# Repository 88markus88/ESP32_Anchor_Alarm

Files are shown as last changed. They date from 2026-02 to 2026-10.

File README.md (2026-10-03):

# Battery operated ESP32 Anchor Alarm with ePaper Display 
Anchor Alarm with LolinLite ESP32, GPS Module, ePaper Display and setting via rotary encoder

At anchor we like to use an anchor alarm app on the mobile phone. Unfortunately that one has a few disadvantages: it uses up the battery quickly, and sometimes Android likes to stop the app for mysterious reasons, particularly if it is not in the front and the screen on. We could also use nachor alarms embedded in other onboard electronics (e.g. AIS), but I find that to inflexible and using too much energy from our precious house batteries.

Thatˋs why I have come up with an alternative, an GPS based anchor alarm with LiPo battery and an ePaper display. It is run by power saving variant of the ESP32 SOC, the Lolin Lite.

| Overview | Routine Screen | Size Comparison
| :--- | :--- | :-- |
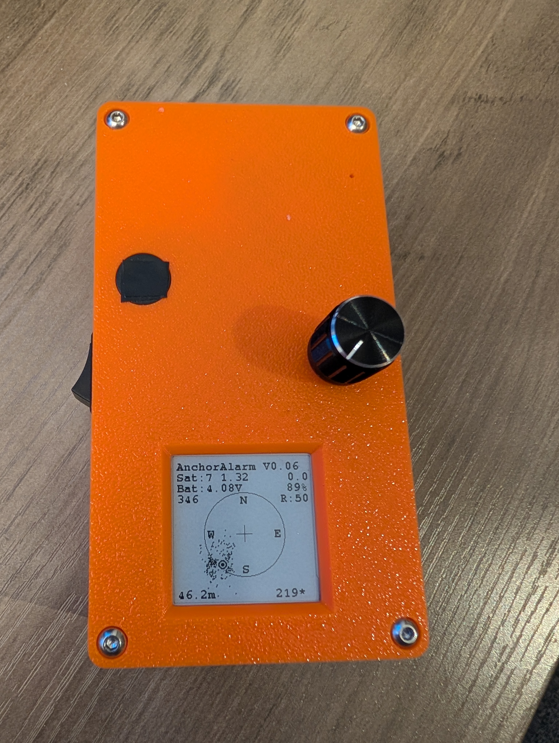
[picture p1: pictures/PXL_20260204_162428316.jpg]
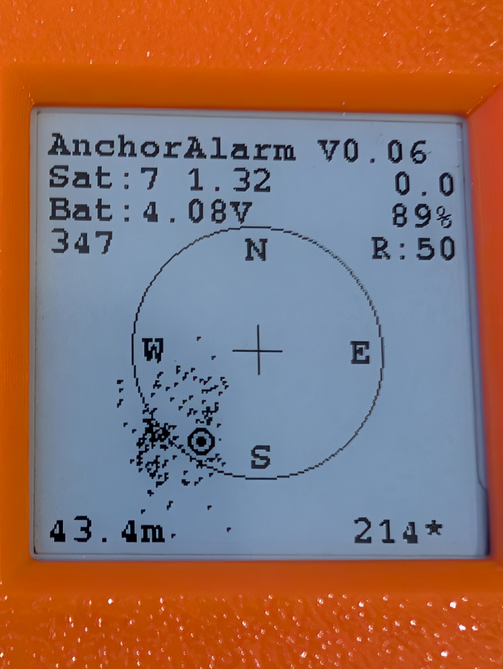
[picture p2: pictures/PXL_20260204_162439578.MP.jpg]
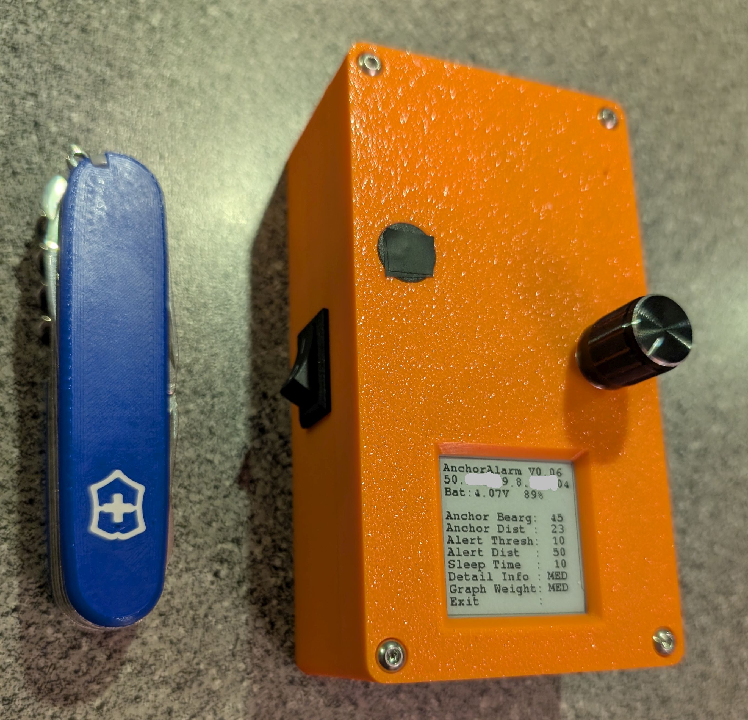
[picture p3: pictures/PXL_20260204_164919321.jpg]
||||

Main components:
- Lolin Lite ESP32: optimized for battery operation while still being inexpensive. It is optimized for battery operation, the module has a very low consumption in deep sleep.
- ePaper Display 1.54" with 200x200 resolution. Sufficiently large for the use case, very low power consumption and pretty good readabilty
- 1800 mAh LiPo battery 52x34x10 mm: sufficient for 30 hours of operation (measured power consumption is 60 mA on avarage)
- GPS module (Ublox NEO-6M, NEO-M8N or alternatively ATGM336H)
- Optional: active GPS antenna
- Rotary Encoder with button for settings
- PCB board: I have recycled a board for the ePaper barograph that I built earlier. I had a few ones left over, all the required pins are exposed (some not properly labeled...)
- 3D printed housing

## Using the Anchor Alarm
Switch on with the toggle switch on the side.
The device will go through a few selftests (including some beeps) 
Then the main menu is shown. Rotate the knob to move through the menu or change values, press it to select.

1: Program name and version<br>
2: Present GPS position in decimal notation<br>
3: Battery voltage and percentage<br>
5: Anchor Bearing - True compass bearing from boat to anchor<br>
6: Anchor Distance - Distance from boat to anchor om meters<br>
7: Alert Threshold - Numeric value that determines how often and how far the boat must be out of the safe circle before an alert is triggered. 10% out of the circle adds 1, 30% out of the circle adds 3 and so on. If the sum of these values is bigger than the Alert Threshold, the alert is triggered<br>
8: Alert Distance - Radius of the safe circle around the anchor in meters <br>
9: Sleeptime - Time in seconds that the device sleeps between measurements (unless there is an alert, then it does not go to sleep)<br>
10: Detail Info - Determines how much data is shown in the watch (routine) screen<br>
11: Graph Weight - Determines how thick the lines and symbols are drawn in the watch screen<br>
12: Power Saving Mode - Determines how aggressive power saving is applied
12: Exit: Exit the menu, change to measurement screen and starts the watch<br>

The watch screen shows the anchor at the center (cross), the safe circle around it and the boat as a "target" in relation to the anchor. Depending on the detail info selected, further information is shown:
- Anchor positon (top) and boat position (bottom). Previous position are shown as dots, size depending on the setting "Graph Weight".
- Number of satellites and HDOP of GPS
- Accumulated alert value (if bigger then Alert Threshold: Alert is triggered)
- Measurement Counter, how often did the device wake up and checked the position
- Battery voltage and percentage
- Distance from and bearing from initial anchor position to boat. (If the boat is SW of the anchor position, the bearing is 235°)

## Power Saving Modes
Since the device has limited battery capacity, power saving is available. Thre modes can be switched in the setup menu. Depending on the GPS module which is installed, different measures are taken:
| Mode | NEO-6M | NEO-M8N |
| --- | --- | --- |
| MIN | 80 MHz, NMEA Msg, Ped | 80 MHz, NMEA Msg, Ped |
| MID | 80 MHz, NMEA Msg, Ped, PSM  | 80 MHz, NMEA Msg, Ped, PM2 |
| MAX | 80 MHz, NMEA Msg, Ped, PM2  | 80 MHz, NMEA Msg, Ped, HF Off|

* 80 MHz: Reduce clock frequency for ESP32 from 240 to 80 MHz
* MEA Msg: Switch off all NMEA messages that are not neede. ONly RMC, GGA, GLL are left on (CFG-MSH
* Ped: Switch the GPS module to pedestrian mode, for better precision at slow speeds (CFG-NAV5)
* PSM: Switch GPS Module to PowerSavineMode (CFG-RXM)
* PM2: Configure extended Power Management to longer updatePeriod (CFG-PM2)
* HF Off: Switch off the GPS module HF section (CFG-RST). Biggest savings, but required time to re-acquire satellites

The effect of power saving (80 MHz) reduces the ESP32 power consumption to ca. 75 mA while not in deep sleep.<br>
The power consumption of the NEO-M8N is reduced to 45 mA in "MIN" mode to 28 mA in "MAX" mode.<br>
Precision of position is better in MIN mode than in MAX mode - depending on the quality of satellite data.

### Sleep Modes and Power Consumption
Power consumption has been measured using a FNIRSI FN-058 USB Power Meter, and theoretical runtime calculated based on a 1800 mA LiPo battery.

NEO-M8N 
| Mode  | Power (20s)|Endurance| Power (50s)|Endurance|
| ---| --- |---|--- |---|
| MIN | 53.0 mA | 33.9 h  | 49.2 mA | 36.6 h  |
| MID | 39.5 mA | 45.6 h  | 38.8 mA | 47.4 h  | 
| MAX | 43.5 mA | 41.4 h  | 36.3 mA | 49.6 h  |

Power consumption for the NEO-6M module is slightly higher, for the ATGM336H still higher, with correspondingly shorter operation times. All modules exceed 24 hours of continuous operation. With a USB power supply connected it is of course infinite.

### Additional Considerations
NEO-M8N appears the best module of all three used: lowest power consumption which can be further reduced using the extensive power management options. It uses satellites from GPS, Beidou, Glonass and Galileo constellations - which means shorter acquisiton times and better fixes. It is also the most expensive module.
Note: in MID mode this module only uses GPS satellites, with somewhat reduced position accuracy. In MIN and MAX mode it uses all three constellations of GPS satellites.

NEO-6M uses only GPS satellites, and has a slightly higher power consumption than NEO-M8N. It also has good power saving options. It is significantly cheapter than the NEO-M8N, and absolutely sufficient if the receiving conditions are good (no mountains or houses around which cover a large part of the sky).

ATGM336H uses GPS, Beidou and Glonass constellations. However, the position walk in my tests was significantly larger than for the NEO-M8N. Power saving options are fairly limited: NMEA messages can be reduced, and "pedestrian" mode can be used. The power saving option had no effect. Consequently this module has the highest power consumption of all three GPS modules. However, the GPS accuracy is good if the conditions are good and an active antenna is used instead of the mini-antenna supplied with the module. When the original antenna is used, acquisiton times can be many minutes if the reception is not good. Prices are low, comparable to the NEO-6M.

### GPS Performance
The following pictures show performance of the GPS with NEO-M8N and ARGM336H modules. The data have been collected in a park, with some trees above. Acquistion was a few seconds in every case. Power save mode "MIN" has been used in the first row, "MID" in the second row. After collecting for a few minutes I have moved about 20 meters to get the ship symbol away from the data point.
|Ublox NEO-M8N| ATGM336H |
|:---|:---|
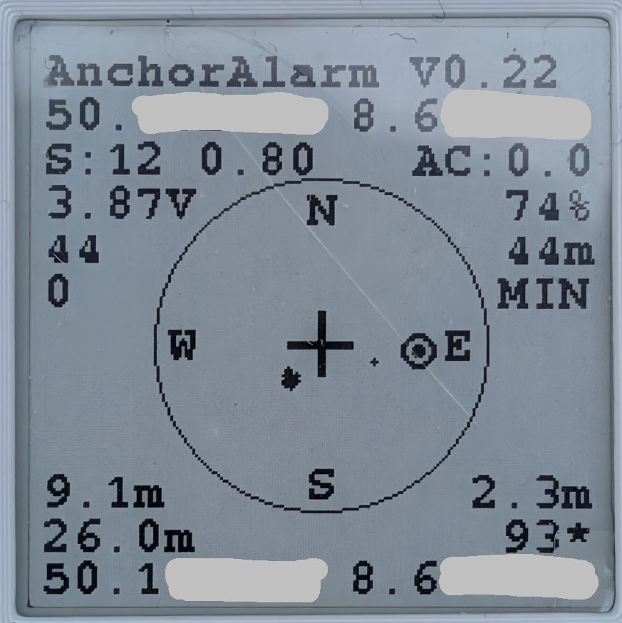
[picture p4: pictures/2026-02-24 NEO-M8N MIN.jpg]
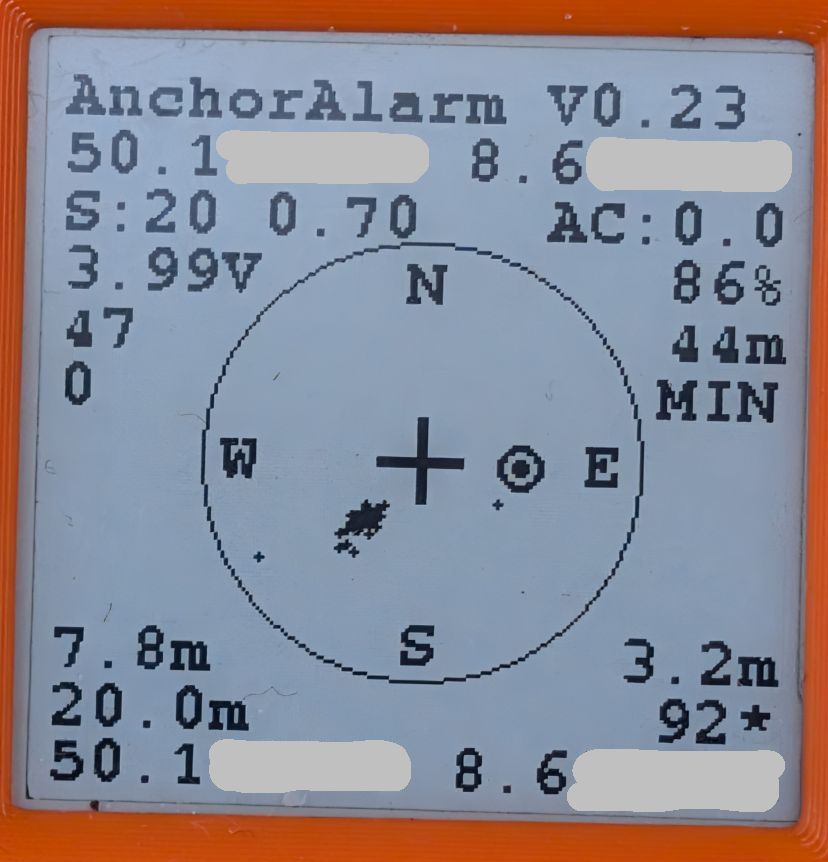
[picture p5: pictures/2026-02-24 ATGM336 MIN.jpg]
|||
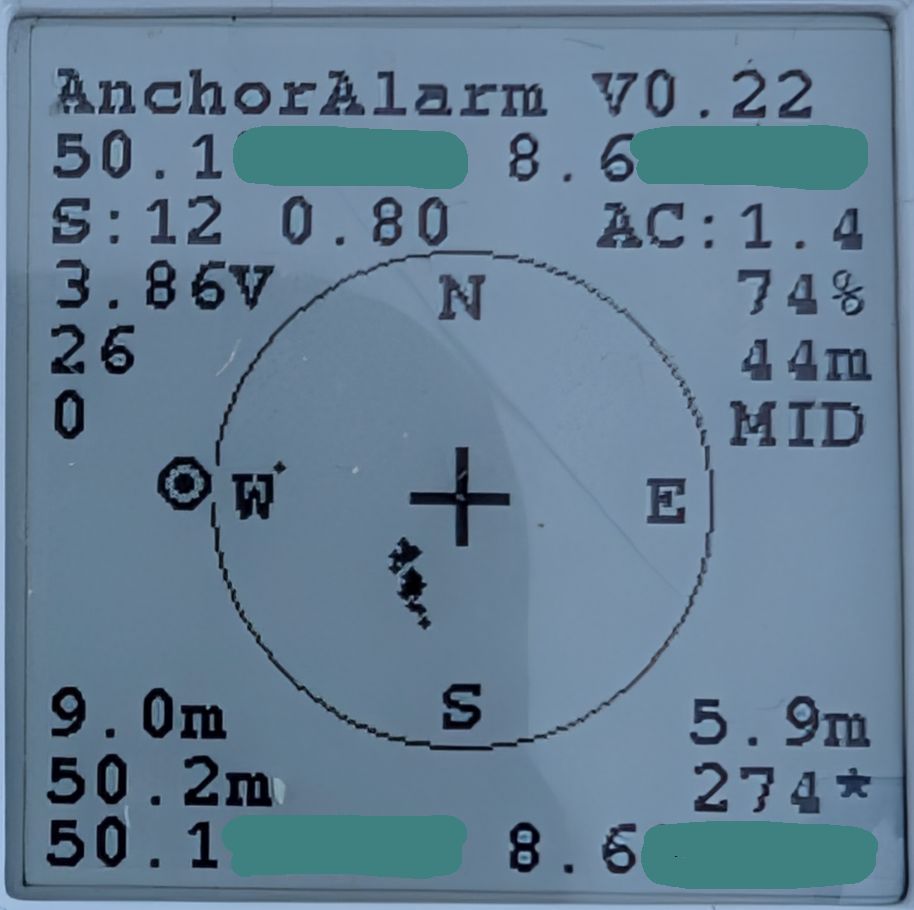
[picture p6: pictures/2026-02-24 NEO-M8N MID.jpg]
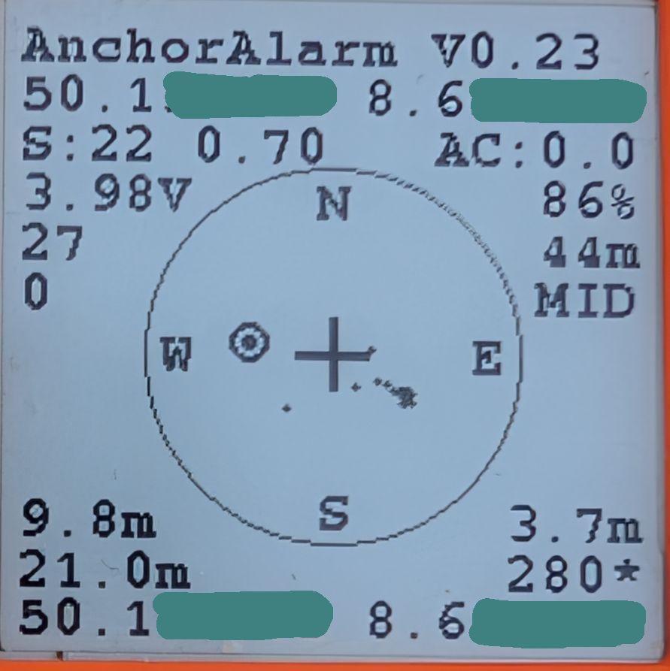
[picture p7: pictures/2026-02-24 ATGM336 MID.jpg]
|||

The NEO-M8N limits itself to 12 satellites, ATGM336H uses as many satellites as it can get. In both cases the results are excellent for "MIN", with a somewhat larger distribution for the ATGM336H. The distribution is a bit wider in the "MID" mode, but still pretty good. The numbers in the third row from the bottom show the standard deviation of the data points in X and Y direction.

## Alert condition 
An alert is triggered if any of the following conditions is true:
- The present boat positon if too far from the original anchor position. Mathematical: (alert value) > (alert threshold). The alert value is accumulated over multiple runs: 10% out of the circle adds 1, 30% out of the circle adds 3 and so on. If the alert threshold is 10, an alert is triggered if the boat is out of the safe circle by more than 100% of the circle radius, or three times in sequence more than 33.3%, or ten times in sequence more than 10%. Whenever the boat returns into the safe circle, alert value is reset to 0.
- No valid GPS position for more than 10 seconds. This is reset as soon as a valid GPS position has been found again
- Battery voltage drops below 3.6V or battery percentage drops below 10%. Even with low voltage the device continues to work, until the battery protection kicks in

An alert can be silenced by pressing the button of the rotary encoder, the device then goes to the menu screen. 

## Schematic
Presently the schematic is available as Fritzing file. 
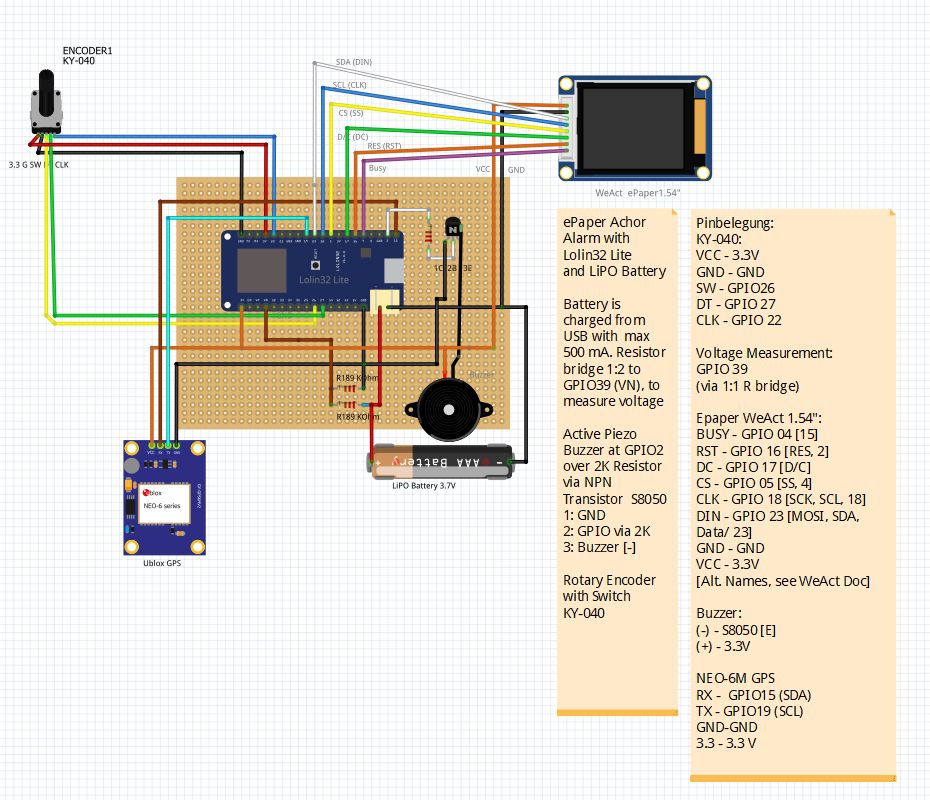
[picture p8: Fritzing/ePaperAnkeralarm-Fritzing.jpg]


## Electrical Connections:
| KY-040| . |
| ----- |--- |
| VCC | 3.3V |
| GND | GND |
| SW  | GPIO26 |
| DT  | GPIO 27 |
| CLK | GPIO 22 |

|Voltage measurement | . |
| ----- | --- |
| GPIO | 39 |

| Epaper | . |
| ----- | --- |
| BUSY | GPIO 04 [15] |
| RST  | GPIO 16 [RES, 2] |
| DC | GPIO 17 [D/C] |
| CS | GPIO 05 [SS, 4] |
| CLK  | GPIO 18 [SCK, SCL, 18] |
| DIN  | GPIO 23 [MOSI, SDA, Data/ 23] |
| GND  | GND |
| VCC  | 3.3V |

| Buzzer  | . |
| ----- | --- |
| Base | via 2 K Ohm -> GPIO2 |

| NEO-6M / M8N GPS | . |
| ----- | --- |
| RX |  GPIO15 (SDA) |
| TX | GPIO19 (SCL) |
| GND | GND |
| 3.3 | 3.3 V |

## PCB - Printed Circuit Board
For my first trials I have re-used a board that I previously used for another project. It does not fit exactly, but all required GPIOs are exposed.
ePaper: is connected as intended
Buzzer: is connected as intended via a S8050 transistor. The base is connected via a 2K resistor to GPIO2
NEO-6M GPS module: the connection initially intended for I2C is used (3.3V, GND, GPIO 15 (labeled SDA) and GPIO19 (labeled SCL)
KY-040 rotary encoder: is connected to 3.3V and GND via a OneWire connector, and to GPIOs 22,26 and 27 via the unmarked spare connectors on the left side of the Lolin Lite board

## Housing
Housing is 3D printed using PLA filament. The STL files for the print are included in the directory "STL"

## Disclaimer
This project is a personal hobbyist project and is provided for educational and experimental purposes only.

All hardware designs, software, firmware, and documentation are provided “as is” and “as available”, without any warranties, express or implied, including but not limited to warranties of merchantability, fitness for a particular purpose, or non-infringement.

The authors and contributors shall not be held liable for any direct or indirect damages, including but not limited to hardware damage, data loss, personal injury, fire, electrical hazards, or legal issues arising from the use, misuse, or inability to use this project.

This project is not intended for use in safety-critical, medical, automotive, industrial, or commercial applications.

You are solely responsible for verifying the correctness, safety, and suitability of this project for your use case, as well as ensuring compliance with all applicable laws, regulations, and standards.

Use this project at your own risk.

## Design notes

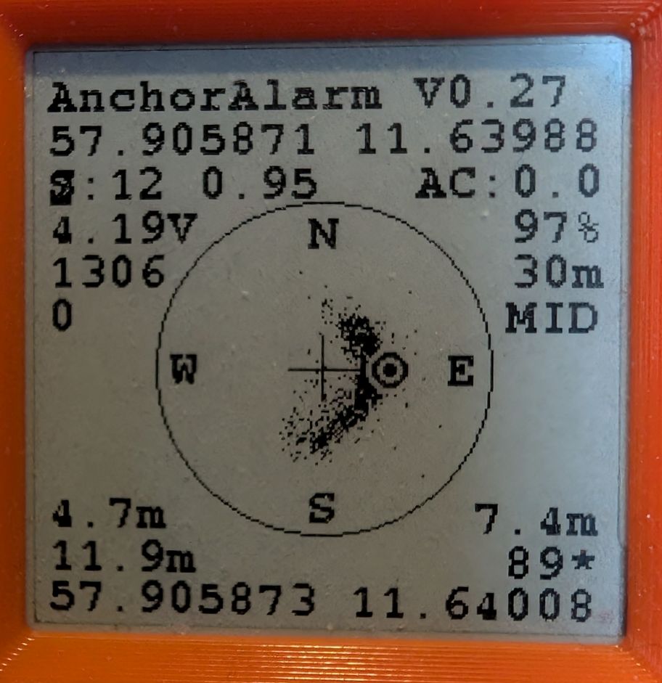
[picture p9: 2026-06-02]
pictures/Guard Screen Jun 2026.jpg

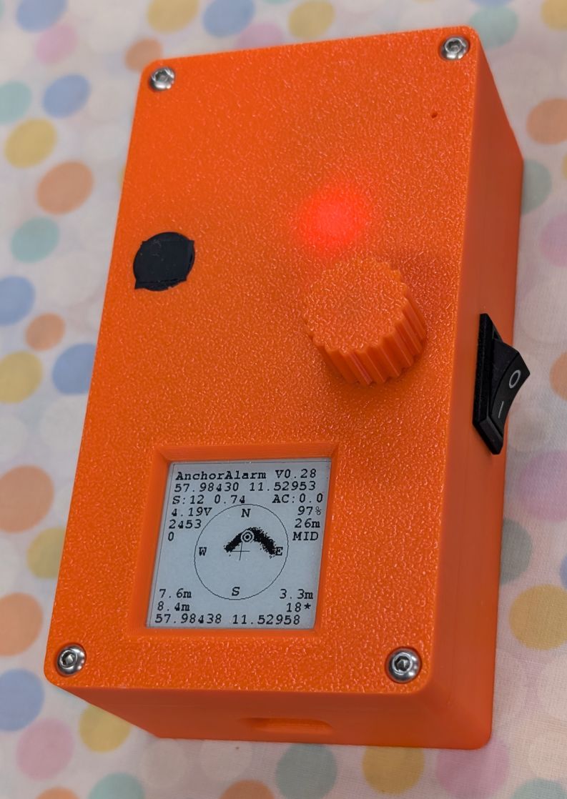
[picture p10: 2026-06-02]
pictures/Geräteansicht Jun 2026.jpg

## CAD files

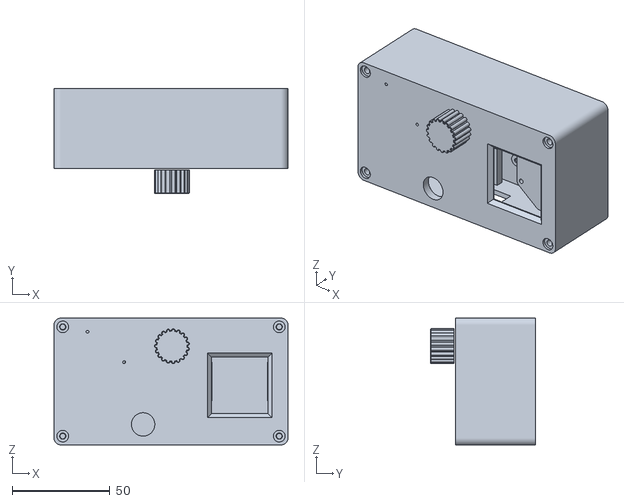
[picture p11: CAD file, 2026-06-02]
STL/Ankeralarm v41.stl
120.0 x 54.0 x 65.0

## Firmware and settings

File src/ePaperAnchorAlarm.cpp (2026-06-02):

/****************************************************************/
// ePaperAnchorAlarm by. M. Preidel
/****************************************************************/

#include <Arduino.h>
#include <math.h>

//**** ESP32 sleep and rtc memory (which survives deep sleep)
#include "esp_sleep.h"
#include "driver/rtc_io.h"

#include <lib/SimpleTimer.h>        // Simple Timer, used instead of Blynk timer for virtuino
SimpleTimer gpsTimer;
int gpsTimerHandle=1;

// ** rotary encoder lib
#include <ESP32Encoder.h>
#define ENCODER_CLK_PIN 22 //25
#define ENCODER_DT_PIN 27
#define ENCODER_SW_PIN 26

// button stuff from ePaperBarograf
#define BUTTON1 GPIO_NUM_26
struct Button {
  const uint8_t PIN;
  uint32_t numberKeyPresses;
  bool pressed;
};
volatile Button button1 = {ENCODER_SW_PIN, 0, false};

void ARDUINO_ISR_ATTR button1Handler();

// include bounce2 library for button debouncing
#include <Bounce2.h>
Bounce button = Bounce();

// GPIO for measurement of voltage
#define VOLTAGE_PIN 39

// TinyGPSPlus library for GPS handling
#include <TinyGPSPlus.h>
// #include <SoftwareSerial.h>

// float volt, percent;                    // battery voltage and percent fill degree

static const int RXPin = 19, TXPin = 15; //22;
static const uint32_t GPSBaud = 9600;

TinyGPSPlus gps;  // The TinyGPSPlus object
HardwareSerial gpsSerial(1); // The serial connection to the GPS device

// for tests latitude and longitude of start position
double startLat = 0.0;
double startLon = 0.0;
double anchorDistance_m = 23;
double anchorBearing_deg = 45.0;
double anchorLat = 0.0;
double anchorLon = 0.0;

// ADC calibration stuff
// https://www.reddit.com/r/esp32/comments/1g4ma01/esp32_s3_adc/?rdt=46482
#include <esp_adc_cal.h>

#if CONFIG_IDF_TARGET_ESP32
#define ADC_EXAMPLE_CALI_SCHEME     ESP_ADC_CAL_VAL_EFUSE_VREF
#elif CONFIG_IDF_TARGET_ESP32S3
#define ADC_EXAMPLE_CALI_SCHEME     ESP_ADC_CAL_VAL_EFUSE_TP_FIT
#endif
#define VREF 1100  // Reeference voltag. used if no data in EFUSE

// *** lib for permanent data storage in EEPROM
// https://randomnerdtutorials.com/esp32-save-data-permanently-preferences/
// if these defines are set, preferences are written / saved to eeprom. 
// otherwise just from RTC storage (survives deep sleep)
#define WRITE_PREFERENCES
#define READ_PREFERENCES
#include <Preferences.h>
Preferences preferences; // object for preference storage in EEPROM
#define prefIDENT "AnchorAlarm1" // unique identifier for preferences

// header file mit #defines, forward declarations, "extern" declarations von woanders deklarierten globalen var's
// globale variablen und alle anderen #includes sind im .cpp file
#include "ePaperAnchorAlarm.h"
#include "epaperGPS.h" // GPS stuff function declarations
#include "global.h"    // global stuff from other modules

//float volt, percent;                    // battery voltage and percent fill degree

char outstring[maxLOG_STRING_LEN];      // for serial and other debug output

//----------------------- measurement data variables -----------------------
uint32_t startTimeMillis; 

ESP32Encoder encoder;  // rotary encoder object

// measurement data, stored in RTC memory which survives the deep sleep. ESP32 has 8 K, used for this 5448 Bytes
RTC_DATA_ATTR measurementData wData;

// screen colors
RTC_DATA_ATTR uint32_t fgndColor;
RTC_DATA_ATTR uint32_t bgndColor;

// determine after how many partial updates a full update of the epaper is to be done
// 1: always full update
#ifdef LOLIN32_LITE
  #define FULL_UPDATE_INTERVAL  10
#endif

// GPIO definition for battery voltage reading
#define VOLTAGE_PIN 39

// GPIO definition for buzzer
#define BUZZER_PIN 2

// test control variables
bool testWelcomeMessage = false;
bool testRotaryEncoder = false;
bool testGPSModule = false;
bool testBuzzer = true;
bool testDisplayModule = false;
bool testBatteryVoltageReading = true;


/**************************************************!
   @brief    logOut()
   @details  Function create log output
   @return   void
***************************************************/
void logOut(int logLevel, char* str)
{
  char safeStr[maxLOG_STRING_LEN+10];
  static uint32_t logCnt = 0;
  // for safety: ensure zero termination well before the end of the string
  // crashes with static strings.
  // str[maxLOG_STRING_LEN-1]=0;
  if(logLevel <= logLEVEL){
    strncat(safeStr, str, maxLOG_STRING_LEN-1); // copy limited number of characters only
    sprintf(safeStr,"%ld %s",logCnt,str);
    //Serial.println(str);
    Serial.println(safeStr);
    logCnt++;
  }
}


/**************************************************!
   @brief    getChargeLevelFromVolts
   @details  Function convert voltage to battery charge level
   @details  see https://github.com/pangodream/18650CL/blob/master/src/Pangodream_18650_CL.cpp
   @param    volts : battery voltage in volts
   @return   int   : battery fill percentage as integer, 0..100
***************************************************/

int getChargeLevelFromVolts(double volts){
  //Array with voltage - charge definitions
  double _vs[] ={3.200,                                                     // 0
    3.250, 3.300, 3.350, 3.400, 3.450, 3.500, 3.550, 3.600, 3.650, 3.700,   // 1-10
    3.703, 3.706, 3.710, 3.713, 3.716, 3.719, 3.723, 3.726, 3.729, 3.732,   // 11-20
    3.735, 3.739, 3.742, 3.745, 3.748, 3.752, 3.755, 3.758, 3.761, 3.765,   // 21-30
    3.768, 3.771, 3.774, 3.777, 3.781, 3.784, 3.787, 3.790, 3.794, 3.797,   // 31-40
    3.800, 3.805, 3.811, 3.816, 3.821, 3.826, 3.832, 3.837, 3.842, 3.847,   // 41-50
    3.853, 3.858, 3.863, 3.868, 3.874, 3.879, 3.884, 3.889, 3.895, 3.900,   // 51-60
    3.906, 3.911, 3.917, 3.922, 3.928, 3.933, 3.939, 3.944, 3.950, 3.956,   // 61-70
    3.961, 3.967, 3.972, 3.978, 3.983, 3.989, 3.994, 4.000, 4.008, 4.015,   // 71-80
    4.023, 4.031, 4.038, 4.046, 4.054, 4.062, 4.069, 4.077, 4.085, 4.092,   // 81-90
    4.100, 4.111, 4.122, 4.133, 4.144, 4.156, 4.167, 4.178, 4.189, 4.200};  // 91-100

 int idx = 50;
 int prev = 0;
 int half = 0;
 if (volts >= 4.2){
   sprintf(outstring,"getChargeLevelFromVolts converted %f [V] to %d [%%]", volts, 100);
   logOut(2, outstring);
   return 100;
 }
 if (volts <= 3.2){
    sprintf(outstring,"getChargeLevelFromVolts converted %f [V] to %d [%%]", volts, 0);
    logOut(2, outstring);
   return 0;
 }
 while(true){
   half = abs(idx - prev) / 2;
   prev = idx;
   if(volts >= _vs[idx]){
     idx = idx + half;
   }else{
     idx = idx - half;
   }
   if (prev == idx){
     break;
   }
  }
  sprintf(outstring,"getChargeLevelFromVolts converted %f [V[] to %d [%%]", volts, idx);
  logOut(2, outstring);
  return idx;
}

/**************************************************!
   @brief    readBatteryVoltage
   @details  Function read battery voltage and percentage
   @details  Uses 3 methods to measure and calculated values
   @param    float* volts : battery voltage in volts
   @param    float* percent : battery filling status in percent of full
   @return   boolean true if calculation successful
***************************************************/

boolean readBatteryVoltage(float* percent, float* volt)
{
  uint32_t raw, millivolts1, millivolts2;

  float voltArduino, voltESP, voltDirect;
  float percentFit1, percentFit2, percent_direct, percentTable;

  esp_adc_cal_characteristics_t adc_chars;

  *percent = 100;
  pinMode(VOLTAGE_PIN, INPUT);

   uint32_t vRef = VREF; // default VREF for voltage measurement
  //uint32_t raw = analogRead(VOLTAGE_PIN);

   // Prüft, ob und welche eFuse-Daten Kalibrationsdaten vorhanden sind
  esp_adc_cal_value_t efuse_config = esp_adc_cal_characterize(
      ADC_UNIT_1, ADC_ATTEN_DB_12, ADC_WIDTH_BIT_12, vRef, &adc_chars);
  if (efuse_config == ESP_ADC_CAL_VAL_EFUSE_TP) 
    logOut(2, (char*)"ESP_ADC_CAL_VAL_EFUSE_TP : Two-Point Calibration from eFuse");
  if (efuse_config == ESP_ADC_CAL_VAL_EFUSE_VREF) 
    logOut(2, (char*)"ESP_ADC_CAL_VAL_EFUSE_VREF: eFuse Vref Used");
  if (efuse_config == ESP_ADC_CAL_VAL_DEFAULT_VREF)
    logOut(2, (char*)"ESP_ADC_CAL_VAL_DEFAULT_VREF: Your Provided Default Vref Is Used");
  if (efuse_config == ESP_ADC_CAL_VAL_EFUSE_TP_FIT)
    logOut(2, (char*)"ESP_ADC_CAL_VAL_EFUSE_TP_FIT: Curve fitting based on eFuse data");

  // arduino method of voltage reading 
  millivolts1 = 2 * analogReadMilliVolts(VOLTAGE_PIN); // 1:1 divider, so multiply by two
  voltArduino = (float)millivolts1 / 1000.0;

  // esp method of voltage reading
  raw = analogRead(VOLTAGE_PIN);
  millivolts2 = 2* esp_adc_cal_raw_to_voltage(raw, &adc_chars); // 1:1 divider, so multiply by two
  voltESP = (float)millivolts2 / 1000.0;
  
  sprintf(outstring,"millivolts1: %ld raw: %ld, millivolts2: %ld (default vRef: %ld) efuse_config: %ld",
    millivolts1, raw, millivolts2, vRef, efuse_config);
  logOut(2,outstring);

  // Original, works well on Lolin32
  //raw = analogRead(VOLTAGE_PIN);// / 4096.0 * 7.23;      // LOLIN D32 (no voltage divider need already fitted to board.or NODEMCU ESP32 with 100K+100K voltage divider
  voltDirect= (float)raw / 4096.0 * 7.23;

  //float voltage = analogRead(39) / 4096.0 * 7.23;    // NODEMCU ESP32 with 100K+100K voltage divider added
  //float voltage = analogRead(A0) / 4096.0 * 4.24;    // Wemos / Lolin D1 Mini 100K series resistor added
  //float voltage = analogRead(A0) / 4096.0 * 5.00;    // Ardunio UNO, no voltage divider required

  // select which voltage value to use
  *volt= voltESP;

  // original percent calculation from curve fitting
  percentFit1 = 2808.3808 * pow(*volt, 4) - 43560.9157 * pow(*volt, 3) + 252848.5888 * pow(*volt, 2) - 650767.4615 * *volt + 626532.5703;
  if(percentFit1<0) percentFit1 =0; // to ensure that the above formula does not produce negative values, as it does slightly above 3.5V
  if (*volt > 4.19) percentFit1 = 100;
  else if (*volt <= 3.50) percentFit1 = 0;

  // Berechnung von reddit https://www.reddit.com/r/esp32/comments/1dybanl/measuring_battery_levels/
  // percent calculation from another curve fitting
  double v = *volt;
  percentFit2 = -  144.9390 * v*v*v + 1655.8629 *v*v - 6158.8520 * v + 7501.3202;
  percentFit2 = max((float)0.0, percentFit2);
  percentFit2 = min((float)100.0, percentFit2);

  // get percent value from table, based on measurement. See above.
  percentTable = (float)getChargeLevelFromVolts(*volt);

  sprintf(outstring, "Voltage from GPIO: %d  raw: %d voltESP: %3.2f voltArduino: %3.2f voltDirect: %3.2f percentFit1: %3.1f percentFit2 %3.1f percentTable: %3.1f",
                                VOLTAGE_PIN,     raw,voltESP,       voltArduino,       voltDirect,       percentFit1,       percentFit2,      percentTable);
  logOut(2,outstring);

  // use percent3 from table
  *percent = percentTable;
  sprintf(outstring,"Used Volt: %3.2f Used Percent %3.1f", *volt, *percent);
  logOut(2,outstring);
  return(true);
}


/*************************** getBatteryCapacity ************************** */
/*
int readBatteryVoltageOld(float* percent, float* volt)
{
  uint16_t readval;
  uint32_t millivolts1, millivolts2;

  float volt_arduino, volt_esp, volt_direct;
  float percent_arduino, percent_esp, percent_direct, percent_table;

  esp_adc_cal_characteristics_t adc_chars;

  *percent = 100;
  pinMode(VOLTAGE_PIN, INPUT);

  // Prüft, ob Curve Fitting (TP_FIT) eFuse-Daten vorhanden sind

  //if (esp_adc_cal_check_efuse(ESP_ADC_CAL_VAL_EFUSE_TP_FIT) == ESP_OK) {
  //   sprintf(outstring,"eFuse Kalibrierdaten (TP_FIT) vorhanden!");
  //} 
  //else {
  //   sprintf(outstring,"Keine eFuse Kalibrierdaten gefunden. Nutze Default-Werte.\n");
  //}
  //logOut(2,outstring);


  uint32_t vRef = VREF;
  //uint32_t raw = analogRead(VOLTAGE_PIN);

  esp_adc_cal_value_t efuse_config = esp_adc_cal_characterize(
      ADC_UNIT_1, ADC_ATTEN_DB_12, ADC_WIDTH_BIT_12, vRef, &adc_chars);
  if (efuse_config == ESP_ADC_CAL_VAL_EFUSE_TP) 
    logOut(2, (char*)"ESP_ADC_CAL_VAL_EFUSE_TP : Two-Point Calibration from eFuse");
  if (efuse_config == ESP_ADC_CAL_VAL_EFUSE_VREF) 
    logOut(2, (char*)"ESP_ADC_CAL_VAL_EFUSE_VREF: eFuse Vref Used");
  if (efuse_config == ESP_ADC_CAL_VAL_DEFAULT_VREF)
    logOut(2, (char*)"ESP_ADC_CAL_VAL_DEFAULT_VREF: Your Provided Default Vref Is Used");
  if (efuse_config == ESP_ADC_CAL_VAL_EFUSE_TP_FIT)
    logOut(2, (char*)"ESP_ADC_CAL_VAL_EFUSE_TP_FIT: Curve fitting based on eFuse data");

  millivolts1 = 2 * analogReadMilliVolts(VOLTAGE_PIN); // 1:1 divider, so multiply by two
  volt_arduino = (float)millivolts2 / 1000.0;

  uint32_t raw = analogRead(VOLTAGE_PIN);
  millivolts2 = 2* esp_adc_cal_raw_to_voltage(raw, &adc_chars); // 1:1 divider, so multiply by two
  volt_esp = (float)millivolts2 / 1000.0;
  
  sprintf(outstring,"millivolts1: %ld raw: %ld, millivolts2: %ld (default vRef: %ld) efuse_config: %ld",
    millivolts1, raw, millivolts2, vRef, efuse_config);
  logOut(2,outstring);

  // Berechnung von reddit https://www.reddit.com/r/esp32/comments/1dybanl/measuring_battery_levels/
  double v = (double)millivolts2 / 1000.0;
  double percent2 = -  144.9390 * v*v*v + 1655.8629 *v*v - 6158.8520 * v + 7501.3202;
  percent2 = max(0.0, percent2);
  percent2 = min(100.0, percent2);

  // Original, works well on Lolin32
  readval = analogRead(VOLTAGE_PIN);// / 4096.0 * 7.23;      // LOLIN D32 (no voltage divider need already fitted to board.or NODEMCU ESP32 with 100K+100K voltage divider
  volt_direct= (float)readval / 4096.0 * 7.23;
  *volt= volt_direct;
  //float voltage = analogRead(39) / 4096.0 * 7.23;    // NODEMCU ESP32 with 100K+100K voltage divider added
  //float voltage = analogRead(A0) / 4096.0 * 4.24;    // Wemos / Lolin D1 Mini 100K series resistor added
  //float voltage = analogRead(A0) / 4096.0 * 5.00;    // Ardunio UNO, no voltage divider required
  
  *percent = 2808.3808 * pow(*volt, 4) - 43560.9157 * pow(*volt, 3) + 252848.5888 * pow(*volt, 2) - 650767.4615 * *volt + 626532.5703;
  
  if(*percent<0) *percent =0; // to ensure that the above formula does not produce negative values, as it does slightly above 3.5V

  if (*volt > 4.19) *percent = 100;
  else if (*volt <= 3.50) *percent = 0;

  int percent3 = getChargeLevelFromVolts(*volt);

  sprintf(outstring, "presently used: GPIO: %d  readval: %d Voltage: %3.2f Percent: %3.1f Percent2 %3.1f Percent3: %d\n",
      VOLTAGE_PIN,readval, *volt,*percent, percent2, percent3);
  logOut(2,outstring);

  // use volt from simplified calculation
  *volt = *volt;
  // use percent3 from table
  *percent = (float)percent3;
  return(true);
}
*/

/**************************************************!
   @brief    handleButtonInterrupt()
   @details  interrupt handling for button pressed on rotary encoder
   @return   void
***************************************************/
volatile bool buttonEvent = false;
volatile unsigned long lastInterruptTime = 0;

void IRAM_ATTR handleButtonInterrupt() {
  unsigned long now = millis();

  // simples Entprellen
  if (now - lastInterruptTime > 400) {
    buttonEvent = true;
    lastInterruptTime = now;
    doParallelBuzzer(1,50,0); // buzzer feedback
  }
}

// possibly better, not yet used 30.1.26
void ARDUINO_ISR_ATTR button1Handler()
{
    if(!button1.pressed)  // avoid repeated pressed to be counted, entprellen
      button1.numberKeyPresses += 1;
    button1.pressed = true;
    //sprintf(outstring, "Button 1 pressed %d\n", button1.numberKeyPresses);
    //logOut(2,outstring);
}

/**************************************************!
   @brief    calcGraphStdDevXY()
   @details  calculate standard deviation of data points (in meters)
   @details  separate for X and Y
   @return   void
***************************************************/
void  calcGraphStdDevXY(){
  double sumX=0.0, sumY=0.0,meanX, meanY, sdX = 0.0, sdY = 0.0;
  uint32_t maxIndex;

  // safeguard agains division by zero if no data points
  if(wData.drawCount < 1){
    wData.stdDevX = 0.0;
    wData.stdDevY = 0.0;
    return;
  }

  // the arrays contain maxDrawBufferLen values. wData.drawCount can be larger
  maxIndex=min(maxDrawBufferLen, wData.drawCount);
  for(int i=0; i < maxIndex;i++){
    sumX += (double)(wData.drawBuffer[i][0]);
    sumY += (double)(wData.drawBuffer[i][1]);
  }
  meanX = sumX /  (double)(maxIndex);
  meanY = sumY /  (double)(maxIndex);
  for(int i=0; i < maxIndex;i++){
    sdX += pow( (double)(wData.drawBuffer[i][0]) -meanX, 2); 
    sdY += pow( (double)(wData.drawBuffer[i][1]) -meanY, 2); 
  }  
  sdX = sqrt(sdX / (double)(maxIndex)); // these SDs are in Pixels
  sdY = sqrt(sdY / (double)(maxIndex));
      
  wData.stdDevX = sdX * wData.alarmDistanceM /  (double)CIRCLE_RADIUS; // in meters
  wData.stdDevY = sdY * wData.alarmDistanceM /  (double)CIRCLE_RADIUS; // in meters

  sprintf(outstring,"StdDevX: %4.1f pix %4.1f m StdDevY: %4.1f pix %4.1f m (AlarmRadius: %3.1f m, %d Pix)", 
    sdX,wData.stdDevX, sdY, wData.stdDevY, wData.alarmDistanceM, CIRCLE_RADIUS);
  logOut(2, outstring);
}


/**************************************************!
   @brief    displayGPSInfo()
   @details  display GPS info, if available
   @return   void
***************************************************/
void displayGPSInfo()
{
  strcpy(outstring,"");

  if (gps.location.isValid())
  {
    double distanceToStart = TinyGPSPlus::distanceBetween(
      gps.location.lat(),
      gps.location.lng(), 
      anchorLat,
      anchorLon);
    double courseToStart = TinyGPSPlus::courseTo(
      gps.location.lat(),
      gps.location.lng(),
      anchorLat,
      anchorLon);
    
    wData.actLat = gps.location.lat();
    wData.actLon = gps.location.lng();
    sprintf(outstring," GPS Sats: #%ld HDOP: %4.2f Dist2Start: %4.2f m Course2Start: %4.2f° Stored Lat/Lon: %6.4f %6.4f",
        gps.satellites.value(),gps.hdop.hdop(), distanceToStart, courseToStart, wData.actLat , wData.actLon);
    logOut(2, outstring);
  }
  else
  {
    //Serial.print(F("INVALID"));
  }

  // Serial.print(F("  Date/Time: "));
  if (gps.date.isValid())
  {
    sprintf(outstring,"%s Date: %02d.%02d.%04d",
        outstring, gps.date.day(),gps.date.month(),gps.date.year());
  }
  else
  {
    //Serial.print(F("INVALID"));
  }

  if (gps.time.isValid())
  {
    sprintf(outstring,"%s Time: %02d:%02d:%02d.%02d",
        outstring, gps.time.hour(),gps.time.minute(),gps.time.second(),gps.time.centisecond());
  }
  else
  {
    //Serial.print(F("INVALID"));
  }

  logOut(2, outstring);
  //Serial.println();
}

#include <math.h>

#define EARTH_RADIUS 6371000.0  // Meter

/**************************************************!
   @brief    gps_offset()
   @details  Calculate new GPS position given start coords, distance and bearing
   @param    double lat1_deg      : start latitude in degrees
   @param    double lon1_deg      : start longitude in degrees
   @param    double distance_m    : distance to move in meters
   @param    double bearing_deg   : bearing in degrees
   @param    double *lat2_deg     : pointer to store resulting latitude in degrees
   @param    double *lon2_deg     : pointer to store resulting longitude in degrees
   @return   void
***************************************************/
void gps_offset(
    double lat1_deg,
    double lon1_deg,
    double distance_m,
    double bearing_deg,
    double *lat2_deg,
    double *lon2_deg
) {
    // Grad → Radiant
    double lat1 = lat1_deg * M_PI / 180.0;
    double lon1 = lon1_deg * M_PI / 180.0;
    double bearing = bearing_deg * M_PI / 180.0;

    // Winkelstrecke
    double delta = distance_m / EARTH_RADIUS;

    // Neue Breite
    double lat2 = asin(
        sin(lat1) * cos(delta) +
        cos(lat1) * sin(delta) * cos(bearing)
    );

    // Neue Länge
    double lon2 = lon1 + atan2(
        sin(bearing) * sin(delta) * cos(lat1),
        cos(delta) - sin(lat1) * sin(lat2)
    );

    // Radiant → Grad
    *lat2_deg = lat2 * 180.0 / M_PI;
    *lon2_deg = lon2 * 180.0 / M_PI;
}
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
void loop() 
{
  // Update the Bounce instance (YOU MUST DO THIS EVERY LOOP)
  /*
  button.update(); // for button debouncing
  int buttonState = button.read();
  if(buttonState == LOW ){
    logOut(2, (char*)"Rotary encoder button pressed.");
    //buzzer(1,50,0); // buzzer feedback
    wData.buttonPressed = true;
  }
  */
  checkButton();

  doRoutineWork();
  gpsTimer.run(); // run gps timer to get data from gps module
};

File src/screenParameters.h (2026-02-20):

//---------------------------- Screen parameters -----------------------------
#define SCREEN_WIDTH  200.0    // Set for landscape mode, don't remove the decimal place!
#define SCREEN_HEIGHT 200.0

#define SCREEN_ROTATION 1     // 0: portrait, 1: landscape, 2: portrait inverted, 3: landscape inverted

// Input data screen parameters
#define HEADER_FONT_SIZE        16
#define HEADER_FONT_DESCENDERS  4   // Teile unter der Basislinie
#define HEADER_FONT_CAPITALS    10  // Teile über der Basislinie
#define DATA_FONT_SIZE          16
#define DATA_FONT_DESCENDERS  4   // Teile unter der Basislinie
#define DATA_FONT_CAPITALS    10  // Teile über der Basislinie
#define HEADER_Y_POS            0
#define HEADER_X_POS            0
#define HEADER_WIDTH            SCREEN_WIDTH
#define HEADER_HEIGHT           2 * HEADER_FONT_SIZE

#define INPUTDATA_FONT_SIZE     16
#define INPUTDATA_FIRST_LINE    4
#define INPUTDATA_Y_POS         INPUTDATA_FIRST_LINE*INPUTDATA_FONT_SIZE - INPUTDATA_FONT_SIZE+1
#define INPUTDATA_X_POS         140
#define INPUTDATA_WIDTH         SCREEN_WIDTH - INPUTDATA_X_POS-1
#define INPUTDATA_HEIGHT        SCREEN_WIDTH - INPUTDATA_Y_POS-1

#define NUM_INPUTDATA_LINES     9

// Watch screen parameters
#define CIRCLE_RADIUS         60
#define CIRCLE_CENTER_X       SCREEN_WIDTH / 2
#define CIRCLE_CENTER_Y       SCREEN_HEIGHT / 2 + 10




//---------------------------- End Screen parameters --------------------------

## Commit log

2026-01-18 V0.01 - nur encoder test
2026-01-31 V0.03 - fully working prototype with sleep
2026-02-03 Voltage Reading & Parallel Buzzer
    [ePaperAnchorAlarm.cpp]
2026-02-05 error correction in preferences
    [ePaperAnchorAlarm.cpp]
2026-02-05 Error corrections in preferences reading
    [ePaperAnchorAlarm.cpp]
2026-02-06 Drawing and Menu improved. Added STL and pictures
    [Ankeralarm.stl]
2026-02-06 Update README with schematic and electrical connections
    Added schematic and electrical connection details for components.
2026-02-06 Added Fritzing file and PCB Gerber files
2026-02-06 Update README with schematic and PCB details
    Added PCB section detailing connections and reused board.
2026-02-06 Add disclaimer for device usage and warranties
    Added a disclaimer about the device's nature and usage.
2026-02-07 Power Save MOde and message reduction on GPS - no savings
2026-02-16 Power saving optimized & selectable via menu
2026-02-17 Enhance README with Power Saving Modes information
    Added Power Saving Modes section with details on power management for GPS modules.
2026-02-17 Update README with voltage measurement details
    Add voltage measurement section to electrical connections
2026-02-17 Fix formatting in README for power modes and connections
    Corrected formatting issues in the power saving modes and electrical connections sections.
2026-02-17 Improve formatting of power consumption details in README
    Added HTML line breaks to power consumption details for better formatting.
2026-02-17 NEO-M8N power save mode "MID" as per app note
2026-02-18 Messaging corrected. Reset powerSaveMode()
    [ePaperAnchorAlarm.cpp]
2026-02-23 Correction MAX powerSave for M8N. ATGM336H included
    [ePaperAnchorAlarm.cpp]
2026-02-24 Revise GPS module details and power consumption info
    Updated GPS module descriptions and added power consumption details for different modes. Included additional considerations for NEO-M8N, NEO-6M, and ATGM336H modules.
2026-02-24 Revise power consumption details for NEO-M8N
    Updated power consumption table for NEO-M8N module with 20s and 50s sleep modes.
2026-03-02 Power saving from M8N implemented for NEO-6M
    [Ankeralarm v35.stl, Ankeralarm.stl]
2026-06-02 Update STL file V35->V41
    [Ankeralarm v35.stl, Ankeralarm v41.stl]
2026-06-03 Update Fritzing schematic
2026-10-03 Clarify battery specifications in README
    Updated battery specifications with dimensions for clarity.
